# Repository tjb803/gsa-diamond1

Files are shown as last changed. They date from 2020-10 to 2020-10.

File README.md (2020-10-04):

# gsa-diamond1

## Simple Stereo Hi-Fi Amplifier

This is a simple Hi-Fi Stereo amplifier project. The intention 
of the project is to produce something that is simple for
anyone to build without special tools, yet can both sound good
and look good.

Please take a look at the project pages [link TBD] for more details
and pictures of completed examples.

The project is based around the Texas Instruments LM1876
single chip amplifier with a pre-amp section providing a volume 
and balance control and push-button selection of up to four 
input sources and standby mode.

### Project Structure

The project schematics and PCBs are generated with
[KiCad](http://kicad-pcb.org/) v5.x

This project is built on four separate PCBs, so the layout and 
structure of the KiCad files needs a little explanation.

* `gsa-diamond1/`  
  This is the project root.  The important files include:
  * `gsa-d1.pro`  
     The main KiCad project control file.

  * `gsa-d1.sch`  
     The schematic for the whole project. This includes a 
     hierarchical subsheet for each PCB. The subsheets themselves
     are stored in a set of subdirectories and can be processed 
     as separate single-PCB projects.

  * `gsa-d1-pcb.kicad_pcb`  
     An outline PCB that can be used to combine the three main
     project PCBs into single 100x100mm board for production.

* `gsa-diamond1/p-amp/`  
   Files for the _Power Amp_ part of the project. Includes the 
   schematic subsheet (written from the main project schematic) and 
   the netlist and PCB specific to this assembly.

* `gsa-diamond1/c-pre/`  
   Files for the _Pre Amp Controls_ part of the project. Includes the 
   schematic subsheet (written from the main project schematic) and 
   the netlist and PCB specific to this assembly.

* `gsa-diamond1/s-inp/`  
   Files for the _Input Selector_ part of the project. Includes the 
   schematic subsheet (written from the main project schematic) and 
   the netlist and PCB specific to this assembly.

* `gsa-diamond1/v-pwr/`  
   Files for the _Power Supply_ part of the project. Includes the 
   schematic subsheet (written from the main project schematic) and 
   the netlist and PCB specific to this assembly.
  
_**Note:**_ To generate the netlists that are specific for just one 
of the sub-PCBs, it is necessary to open **eeschema** directly against
the schematic for that subsheet; the main KiCad project manager 
cannot be used for this.

### Prerequisites

The KiCad schematics and board layouts use only symbols and
footprints from the [gsa-lib](https://github.com/tjb803/gsa-lib)
project.  You should install and configure that project first,
ensuring you have the latest version that supports KiCad v5.

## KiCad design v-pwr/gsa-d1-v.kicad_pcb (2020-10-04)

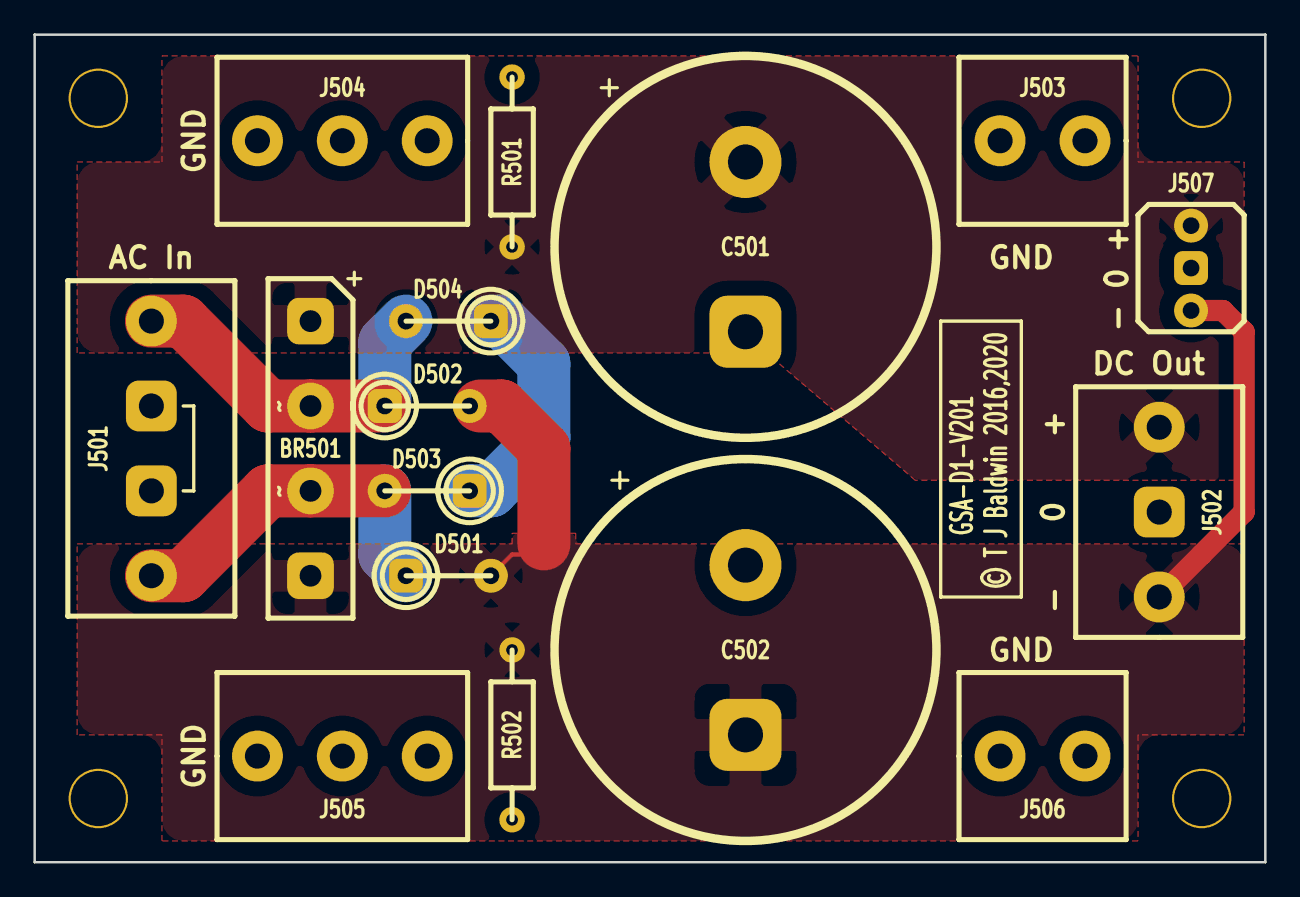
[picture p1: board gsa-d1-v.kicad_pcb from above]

Board: 2 copper layers, 73.7 x 49.5 mm, 20 parts (0 on the bottom side), 5 nets.

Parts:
BR501: BRIDGE; BR-SIL
C501, C502: 4700u; ELEC22R
D501, D502, D503, D504: DIODE; RECT5
H501, H502, H503, H504: HOLE; HOLE33
J501: CONN-4; SCREW4
J502, J504, J505: CONN-3; SCREW3
J503, J506: CONN-2; SCREW2
J507: CONN-3; MOLEX3
R501, R502: 2.7k; RES10

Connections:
/AC1: BR501.a2, D501.k, D503.a, J501.4
/AC2: BR501.a1, D502.k, D504.a, J501.1
/V+: BR501.d2, C501.2, D503.k, D504.k, J502.3, J507.3, R501.2
/V-: BR501.d1, C502.1, D501.a, D502.a, J502.1, J507.1, R502.1
GND: C501.1, C502.2, J501.2, J501.3, J502.2, J503.1, J503.2, J504.1, J504.2, J504.3, J505.1, J505.2, J505.3, J506.1, J506.2, J507.2, R501.1, R502.2

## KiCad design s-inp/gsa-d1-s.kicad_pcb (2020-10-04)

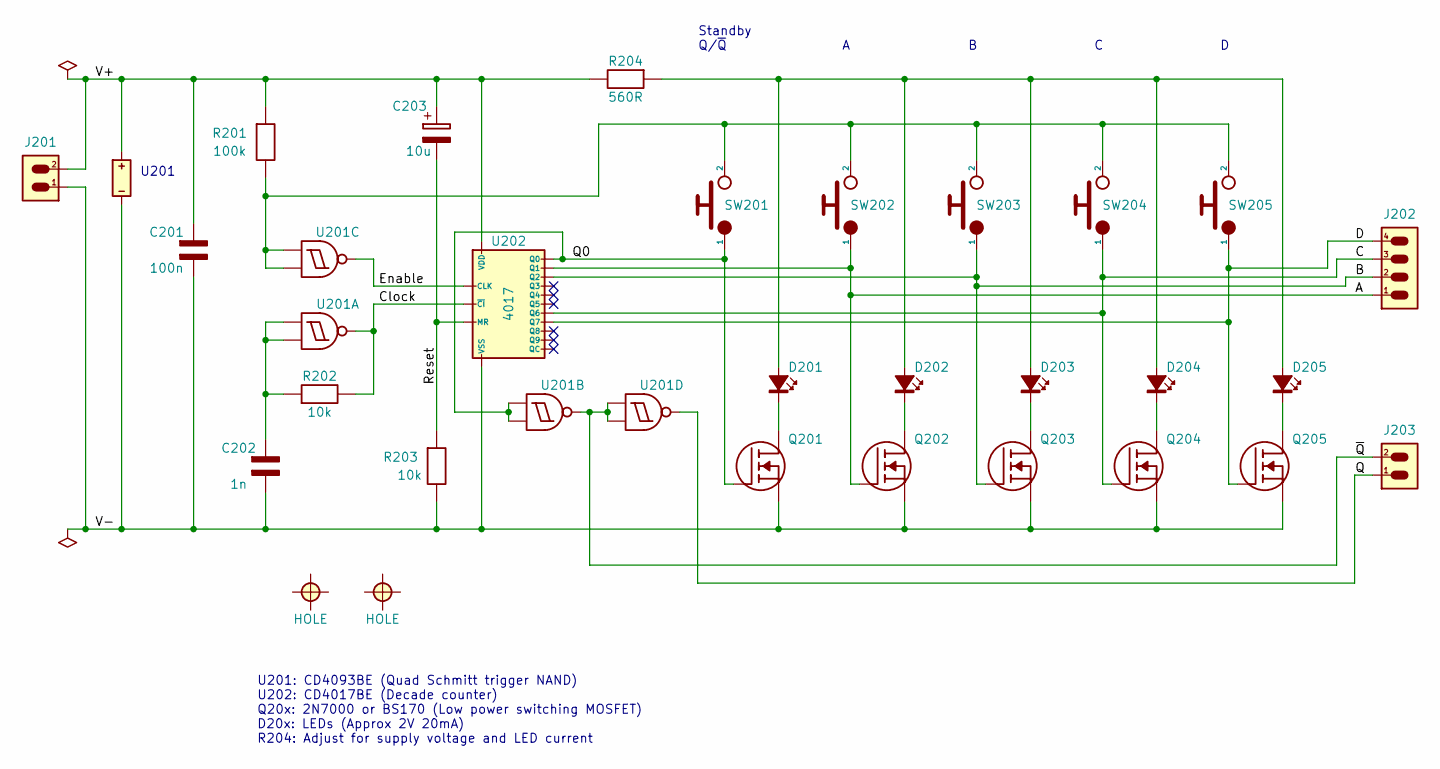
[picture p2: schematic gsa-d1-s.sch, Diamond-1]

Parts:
C201: 100n; CAP725
C202: 1n; CAP-C25
C203: 10u; ELEC4R
D201, D202, D203, D204, D205: LED; LED3
H201, H202: HOLE; HOLE33
J201, J203: CONN-2; MOLEX2
J202: CONN-4; MOLEX4
Q201, Q202, Q203, Q204, Q205: 2N7000; TO92F-SGD
R201: 100k; RES10
R202, R203: 10k; RES10
R204: 560R; RES10
SW201, SW202, SW203, SW204, SW205: SW-PUSH; SW-TACT-ALL
U201: 4093; DIL14
U202: 4017; DIL16

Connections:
/A: J202.1, Q202.g (G), SW202.1, U202.2 (Q1)
/B: J202.2, Q203.g (G), SW203.1, U202.4 (Q2)
/C: J202.3, Q204.g (G), SW204.1, U202.5 (Q6)
/Clock: R202.1, U201.3 (J), U202.13 (~CI)
/D: J202.4, Q205.g (G), SW205.1, U202.6 (Q7)
/Enable: U201.10 (J), U202.14 (CLK)
/Q: J203.1, U201.11 (J)
/Q0: Q201.g (G), SW201.1, U201.5 (A), U201.6 (B), U202.3 (Q0)
/Reset: C203.1 (-), R203.2, U202.15 (MR)
/V+: C201.2, C203.2 (+), J201.2, R201.2, R204.1, U201.14 (V+), U202.16 (VDD)
/V-: C201.1, C202.1, J201.1, Q201.s (S), Q202.s (S), Q203.s (S), Q204.s (S), Q205.s (S), R203.1, U201.7 (V-), U202.8 (VSS)
/~Q: J203.2, U201.4 (J), U201.12 (A), U201.13 (B)
unnamed: C202.2, R202.2, U201.1 (A), U201.2 (B)
unnamed: D201.a (A), D202.a (A), D203.a (A), D204.a (A), D205.a (A), R204.2
unnamed: D201.k (K), Q201.d (D)
unnamed: D202.k (K), Q202.d (D)
unnamed: D203.k (K), Q203.d (D)
unnamed: D204.k (K), Q204.d (D)
unnamed: D205.k (K), Q205.d (D)
unnamed: R201.1, SW201.2, SW202.2, SW203.2, SW204.2, SW205.2, U201.8 (A), U201.9 (B)

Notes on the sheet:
U201: CD4093BE (Quad Schmitt trigger NAND) U202: CD4017BE (Decade counter) Q20x: 2N7000 or BS170 (Low power switching MOSFET) D20x: LEDs (Approx 2V 20mA) R204: Adjust for supply voltage and LED current
Standby Q/~Q
U201

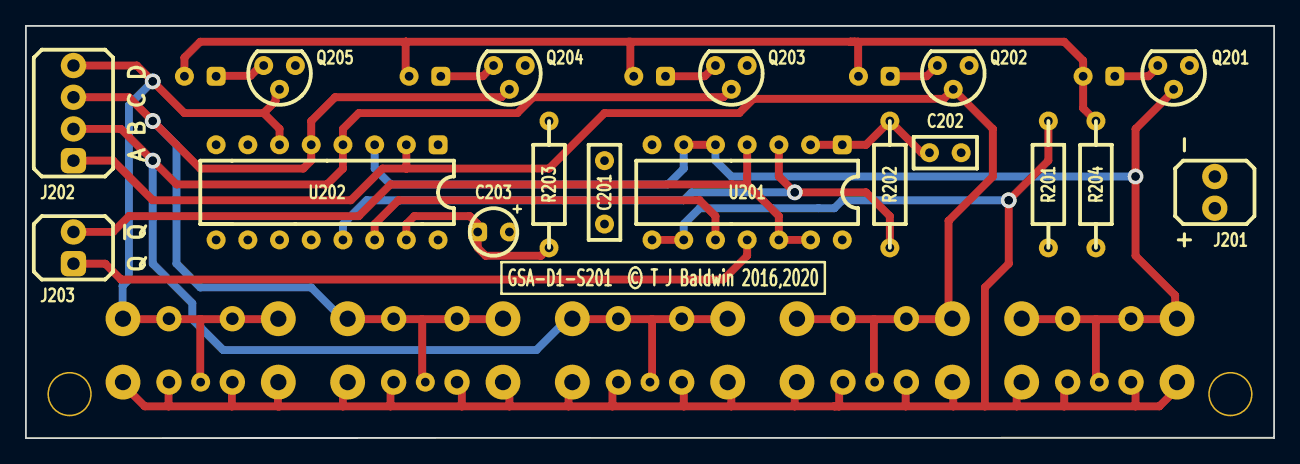
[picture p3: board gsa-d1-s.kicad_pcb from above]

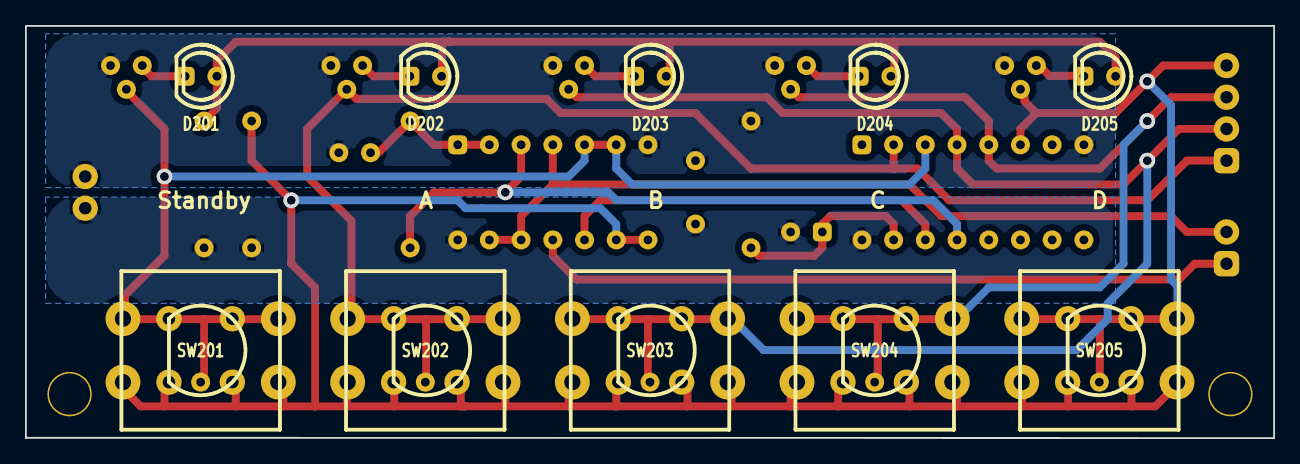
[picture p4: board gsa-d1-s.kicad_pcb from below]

Board: 2 copper layers, 100.0 x 33.0 mm, 29 parts (10 on the bottom side), 20 nets.

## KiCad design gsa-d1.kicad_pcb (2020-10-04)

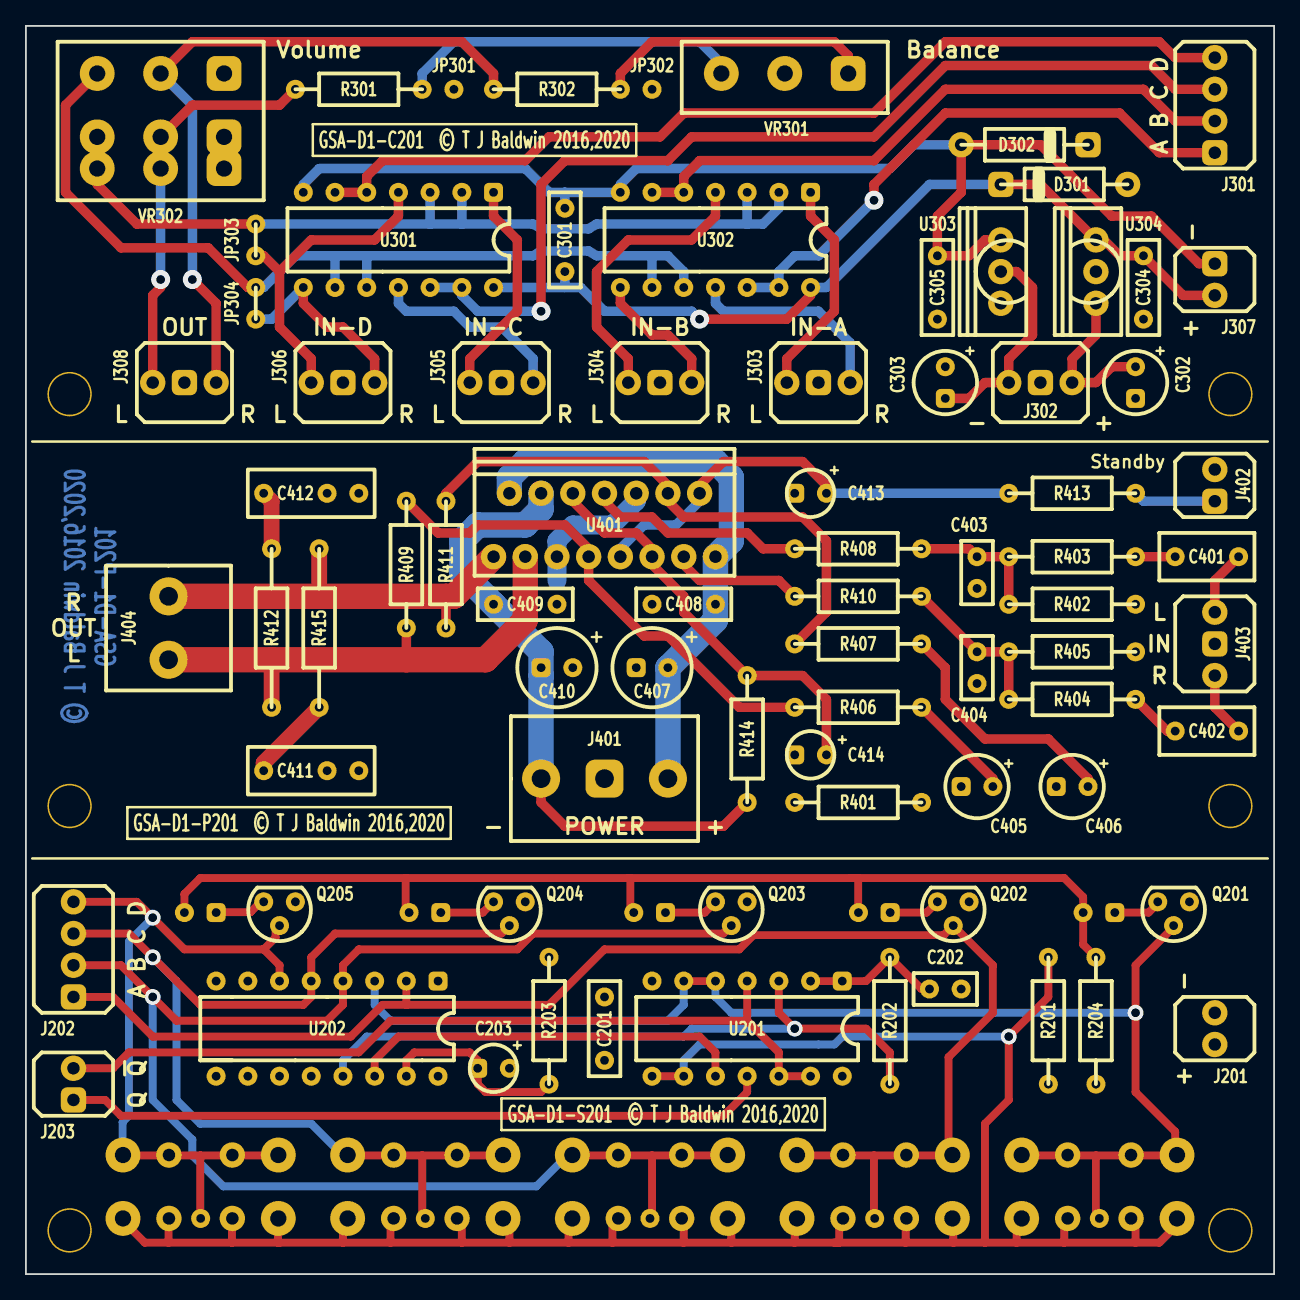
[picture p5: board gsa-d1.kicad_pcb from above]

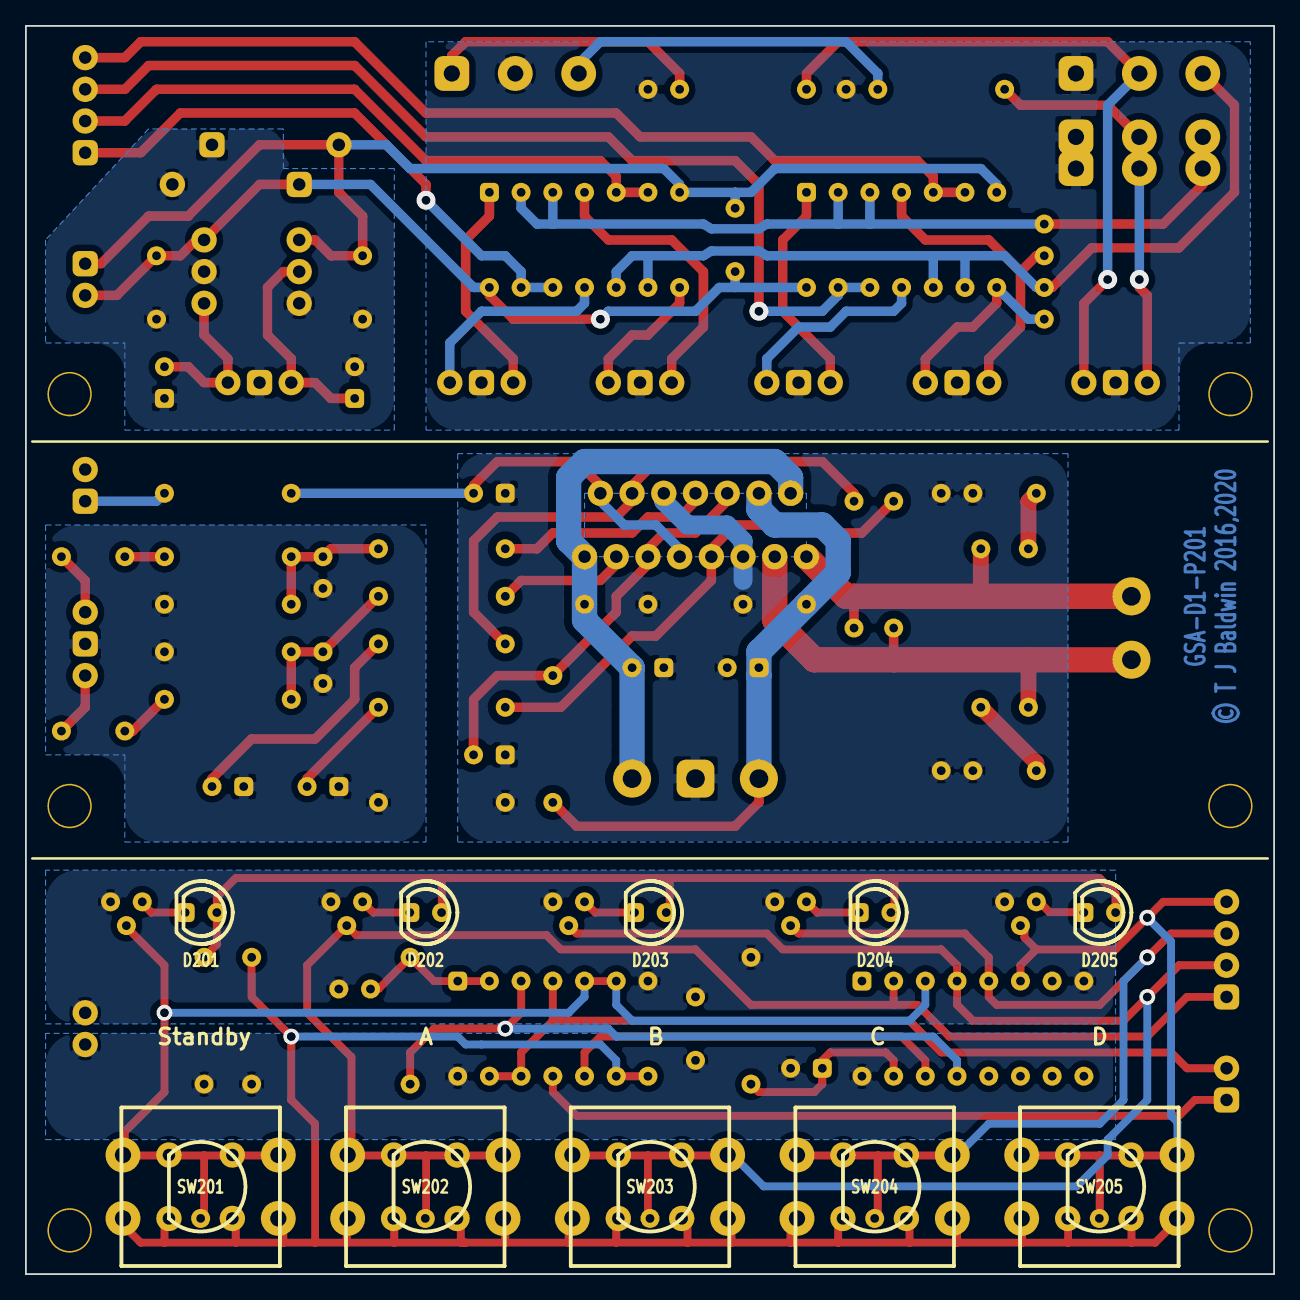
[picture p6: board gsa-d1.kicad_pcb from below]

Board: 2 copper layers, 100.0 x 100.0 mm, 94 parts (10 on the bottom side), 67 nets.

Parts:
C201, C301, C304, C305, C408, C409: 100n; CAP725
C202: 1n; CAP-C25
C203: 10u; ELEC4R
C302, C303: 22u; ELEC5R
C401, C402: 2.2u; CAP740
C403, C404: 220p; CAP-C25
C405, C406: 47u; ELEC5R
C407, C410: 100u; ELEC6R
C411, C412: 100n; CAP-7-10
C413, C414: 47u; ELEC4R
D201, D202, D203, D204, D205: LED; LED3
D301, D302: 1N4001; DIODE10
H201, H202, H301, H302, H401, H402: HOLE; HOLE33
J201, J203, J307, J402: CONN-2; MOLEX2
J202, J301: CONN-4; MOLEX4
J302, J303, J304, J305, J306, J308, J403: CONN-3; MOLEX3
J401: CONN-3; SCREW3
J404: CONN-2; SCREW2
JP301, JP302: PAD; PAD07
JP303, JP304: LINK; LINK2
Q201, Q202, Q203, Q204, Q205: 2N7000; TO92F-SGD
R201: 100k; RES10
R202, R203, R413: 10k; RES10
R204: 560R; RES10
R301, R302: 4.7k; RES10
R401: 5R6; RES10
R402, R405: 47k; RES10
R403, R404, R406, R407, R408, R410: 1k; RES10
R409, R411: 39k; RES10
R412, R415: 4R7; RES12
R414: 18k; RES10
SW201, SW202, SW203, SW204, SW205: SW-PUSH; SW-TACT-ALL
U201: 4093; DIL14
U202: 4017; DIL16
U301, U302: 4066; DIL14
U303: 7905; REG79
U304: 7805; REG78
U401: LM1876; TO220-15
VR301: 22k; POT-OMEG
VR302: 100k; POT-DUAL

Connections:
/A: J202.1, Q202.g, SW202.1, U202.2
/B: J202.2, Q203.g, SW203.1, U202.4
/C: J202.3, Q204.g, SW204.1, U202.5
/Clock: R202.1, U201.3, U202.13
/D: J202.4, Q205.g, SW205.1, U202.6
/Enable: U201.10, U202.14
/Inputs and Pre-Amp/A: J301.1, U302.12, U302.13
/Inputs and Pre-Amp/A-L: J303.3, U302.1
/Inputs and Pre-Amp/A-R: J303.1, U302.11
/Inputs and Pre-Amp/B: J301.2, U302.5, U302.6
/Inputs and Pre-Amp/B-L: J304.3, U302.4
/Inputs and Pre-Amp/B-R: J304.1, U302.8
/Inputs and Pre-Amp/C: J301.3, U301.12, U301.13
/Inputs and Pre-Amp/C-L: J305.3, U301.1
/Inputs and Pre-Amp/C-R: J305.1, U301.11
/Inputs and Pre-Amp/D: J301.4, U301.5, U301.6
/Inputs and Pre-Amp/D-L: J306.3, JP303.2, U301.4
/Inputs and Pre-Amp/D-R: J306.1, JP304.2, U301.8
/Inputs and Pre-Amp/GND-P: C302.1, C303.2, C304.1, C305.2, D301.a, D302.k, J302.2, U303.1, U304.2
/Inputs and Pre-Amp/GND-S: J303.2, J304.2, J305.2, J306.2, J308.2, JP301.0, JP302.0, VR301.2, VR302.1, VR302.4
/Inputs and Pre-Amp/L: JP303.1, U301.2, U301.3, U302.2, U302.3, VR302.6
/Inputs and Pre-Amp/L-Out: J308.3, R301.1, VR302.5
/Inputs and Pre-Amp/R: JP304.1, U301.9, U301.10, U302.9, U302.10, VR302.3
/Inputs and Pre-Amp/R-Out: J308.1, R302.2, VR302.2
/Inputs and Pre-Amp/V+: C301.2, C304.2, D301.k, J307.2, U301.14, U302.14, U304.3
/Inputs and Pre-Amp/V-: C301.1, C305.1, D302.a, J307.1, U301.7, U302.7, U303.3
/Inputs and Pre-Amp/Vin+: C302.2, J302.3, U304.1
/Inputs and Pre-Amp/Vin-: C303.1, J302.1, U303.2
/Power Amp/GND-S: C403.2, C404.2, C405.1, C406.1, J403.2, R401.2, R402.2, R405.2
/Power Amp/L-In: C401.1, J403.3
/Power Amp/L-Out: J404.2, R409.2, R412.2, U401.3
/Power Amp/MT: C414.2, R414.2, U401.6, U401.11
/Power Amp/R-In: C402.1, J403.1
/Power Amp/R-Out: J404.1, R411.2, R415.2, U401.1
/Power Amp/SB: C413.2, R413.1, U401.9, U401.14
/Power Amp/Standby: J402.1, R413.2
/Power Amp/V+: C407.2, C408.1, J401.3, U401.2, U401.15
/Power Amp/V-: C409.1, C410.1, J401.1, R414.1, U401.4
/Q: J203.1, U201.11
/Q0: Q201.g, SW201.1, U201.5, U201.6, U202.3
/Reset: C203.1, R203.2, U202.15
/V+: C201.2, C203.2, J201.2, R201.2, R204.1, U201.14, U202.16
/V-: C201.1, C202.1, J201.1, Q201.s, Q202.s, Q203.s, Q204.s, Q205.s, R203.1, U201.7, U202.8
/~Q: J203.2, U201.4, U201.12, U201.13
GND: C407.1, C408.2, C409.2, C410.2, C411.2, C412.2, C413.1, C414.1, J401.2, R401.1, U401.5, U401.10
unnamed: C202.2, R202.2, U201.1, U201.2
unnamed: C401.2, R403.1
unnamed: C402.2, R404.1
unnamed: C403.1, R402.1, R403.2, R408.1
unnamed: C404.1, R404.2, R405.1, R410.1
unnamed: C405.2, R406.2
unnamed: C406.2, R407.2
unnamed: C411.1, R415.1
unnamed: C412.1, R412.1
unnamed: D201.a, D202.a, D203.a, D204.a, D205.a, R204.2
unnamed: D201.k, Q201.d
unnamed: D202.k, Q202.d
unnamed: D203.k, Q203.d
unnamed: D204.k, Q204.d
unnamed: D205.k, Q205.d
unnamed: R201.1, SW201.2, SW202.2, SW203.2, SW204.2, SW205.2, U201.8, U201.9
unnamed: R301.2, VR301.3
unnamed: R302.1, VR301.1
unnamed: R406.1, R409.1, U401.7
unnamed: R407.1, R411.1, U401.12
unnamed: R408.2, U401.8
unnamed: R410.2, U401.13

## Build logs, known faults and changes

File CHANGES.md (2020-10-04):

## Release 2.0.0
First public release 

## Release 2.0.1
Updated to GSA library v1.1.0

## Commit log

2018-02-27 GSA Diamond-1 Amplifier
    [gsa-d1-c000.kicad_pcb, gsa-d1-c000.sch, gsa-d1-p000.kicad_pcb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]
2018-02-28 Combined PCB
    [gsa-d1.kicad_pcb]
2018-03-03 Minor layout improvements to pre-amp controls
    [gsa-d1-c000.kicad_pcb, gsa-d1-c000.sch, gsa-d1-p000.sch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]
2018-03-11 Reduce size of power supply PCB
    [gsa-d1-c000.sch, gsa-d1-p000.kicad_pcb, gsa-d1-p000.sch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]
2019-05-05 Updated to use KiCad v5
    [gsa-d1-c000.kicad_pcb, gsa-d1-c000.sch, gsa-d1-p000.kicad_pcb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]
2020-10-04 Updated to use gsa-lib v1.1
    [gsa-d1-c.kicad_pcb, gsa-d1-c.sch, gsa-d1-c000.kicad_pcb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]

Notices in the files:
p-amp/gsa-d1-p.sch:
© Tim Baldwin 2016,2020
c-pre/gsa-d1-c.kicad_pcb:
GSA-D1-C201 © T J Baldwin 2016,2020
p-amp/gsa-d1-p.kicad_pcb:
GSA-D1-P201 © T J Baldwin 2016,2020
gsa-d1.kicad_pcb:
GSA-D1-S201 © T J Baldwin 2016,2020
